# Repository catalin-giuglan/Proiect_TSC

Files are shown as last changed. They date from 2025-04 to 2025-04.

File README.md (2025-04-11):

# Proiect TSC

### Schema bloc și fișierul BOM



[Tabel BOM](https://docs.google.com/spreadsheets/d/16zDlMAK-QEJo3e8-mDt3CT91WrjNDixEgXfPSYE8hOI/edit?usp=sharing)

### Componentele au fost procurate de pe:
- [Mouser](https://eu.mouser.com/)
- [Comet](https://www.comet.srl.ro/)

### Examinare 3D a dispozitivului:
- Sketch 43 reprezintă bateria.
- Sketch 44 reprezintă ecranul.
- Pentru a vedea imagini cu dispozitivul, caută în directorul Images al acestui repository.

---

# **Descriere Proiect**  

Acest proiect constă în dezvoltarea unui ebook reader, utilizând **Autodesk Fusion** pentru modelare 3D și **librăria Desk Assistant** pentru proiectarea electronică. În cele ce urmează sunt prezentate etapele principale ale realizării proiectului, de la montarea schematicului, până la integrarea finală și generarea fișierelor necesare.

---

## **1. Instalarea librăriei Desk Assistant**  
Proiectul a început prin instalarea librăriei **Desk Assistant**, care oferă acces la componentele esențiale: rezistențe, condensatori, butoane etc. Această librărie a constituit baza pentru proiectarea și implementarea electronică.

---

## **2. Crearea schematicului**  
Am realizat schematicul în format 2D, conectând cu precizie toate componentele conform cerințelor proiectului. Procesul a inclus:  
- **Respectarea topologiilor și conexiunilor** specificate.  
- Crearea unui design clar pentru implementarea ulterioară a PCB-ului.

---

## **3. Implementarea PCB-ului**  
După finalizarea schematicului, am trecut la proiectarea plăcii PCB (layout-ul):  
- **Poziționarea componentelor** conform dimensiunilor și constrângerilor.  
- **Rutarea circuitelor** pentru conexiuni optime.  
- Validarea designului prin **fișierul DRC** (Design Rule Check), respectând toate constrângerile, cum ar fi grosimea cablurilor pentru fiabilitate.

---

## **4. Modelarea 3D**  
Am creat modelul 3D al proiectului utilizând Autodesk Fusion:  
1. Descărcarea și poziționarea **modelelor 3D** ale componentelor.  
2. Maparea acestora cu corespondențele lor din schematicul 2D.  
3. Integrarea plăcii PCB, bateriei și a display-ului în **carcasa proiectată**.

---

## **5. Generarea fișierelor auxiliare**  
Pentru livrarea proiectului, am generat:  
- **Fișierul BOM** (Bill of Materials), care include lista componentelor utilizate.  
- **Fișierul CAM**, necesar pentru fabricarea plăcii PCB.

## **6. Rezolvarea Issue-urilor semnalate**
Pentru a finaliza a doua etapa a proiectului am:
- Citit cu atentie fiecare issue
- Rezolvat problemele semnalate
- Incarcat din nou fisierele de schematic si PCB
- Incarcat imagini noi care sa demonstreze actualizarea proiectului

---

### Componente Hardware folosite:
- **ESP32-C6**: Microcontroller principal, care asigură conectivitatea și procesarea datelor.
- **E-Paper Display**: Display cu consum redus de energie, conectat prin interfața SPI.
- **Senzor de Mediu BME688**: Măsoară parametrii de mediu și trimite date prin interfața I2C.
- **Memorie NOR Flash 64MB**: Stocare extensibilă pentru fișiere de e-book.
- **Modul RTC DS3231SN**: Oferă funcționalitate de ceas în timp real.
- **Conector USB-C**: Încărcare și transfer de date.
- **Baterie Li-Po**: Alimentare principală a dispozitivului.
- **Conectori pentru SD Card**: Pentru extinderea memoriei și stocarea cărților.

---

### ESP32-C6:
- **GPIO pinii** sunt utilizați pentru conectarea senzorilor și a altor componente periferice.
- **SPI** pentru E-Paper și memorie Flash.
- **I2C** pentru senzorul de mediu.

**Interfețe principale:**
- **SPI**: Conectează ecranul E-Paper și memoria Flash.
- **I2C**: Conectează senzorul BME688 și modulul RTC.
- **UART**: Pentru comunicație serială.

**Pini Utilizați - ESP32-C6:**
- **GPIO16**: TX pentru comunicație serială.
- **GPIO17**: RX pentru comunicație serială.
- **GPIO21**: SDA pentru I2C.
- **GPIO22**: SCL pentru I2C.
- **GPIO18, GPIO19**: SCK și MISO pentru SPI.
- **GPIO5**: Chip Select pentru memorie Flash.
- **GPIO4**: Reset pentru E-Paper.

---

### Probleme și gestionarea erorilor:
- A fost necesara aprobarea a 2 erori de tip "smd-hole", deoarece o piesa era defecta.

- Pentru TP-uri nu am gasit un model 3D online, asa ca a fost nevoie sa folosesc un cilindru cu partea de sus putin rotunjita.

- Am folosit un numar de vias-uri cam mare pentru a evita erorile de overlap.

---

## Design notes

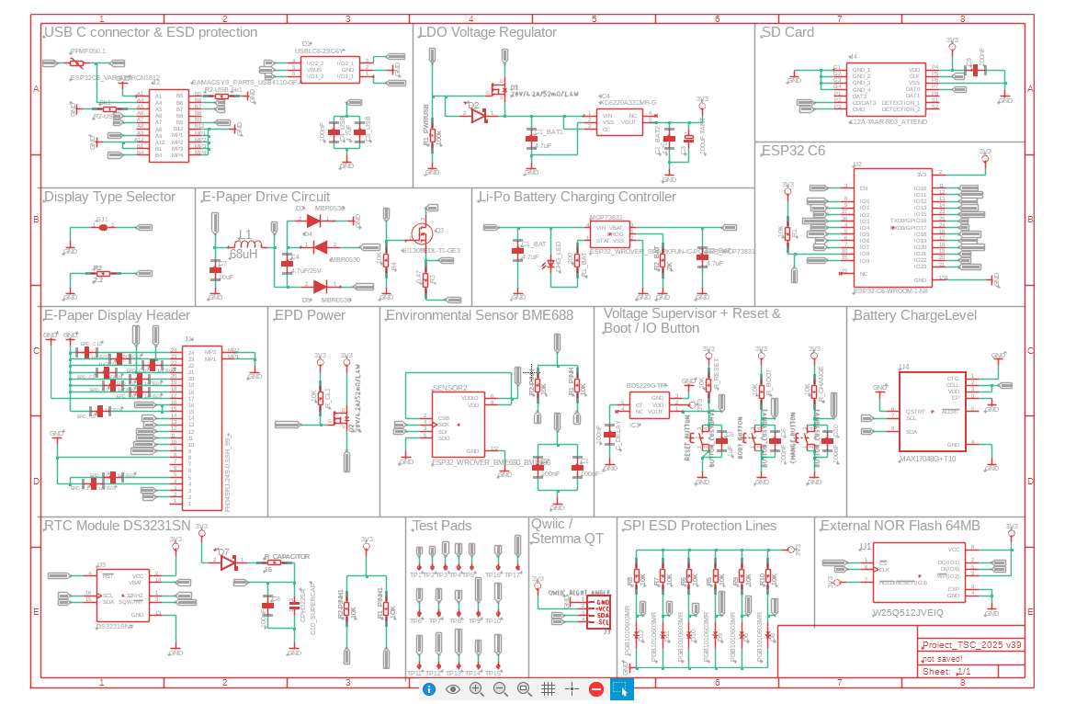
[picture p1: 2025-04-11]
Images/Schematic.png

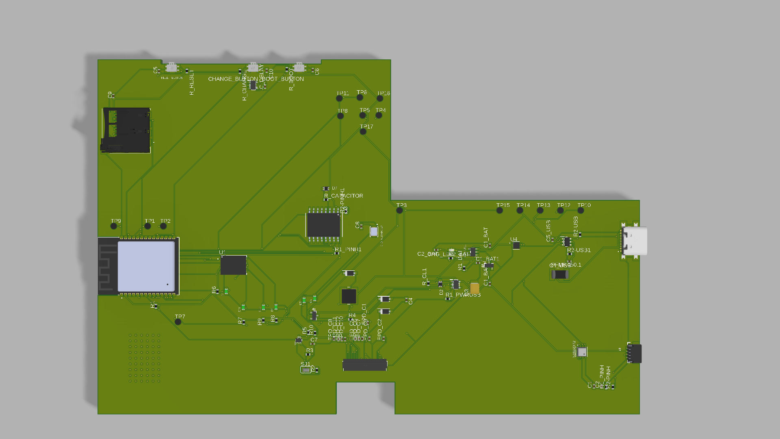
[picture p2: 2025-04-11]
Images/Proiect_TSC_2025 v38_Top.png

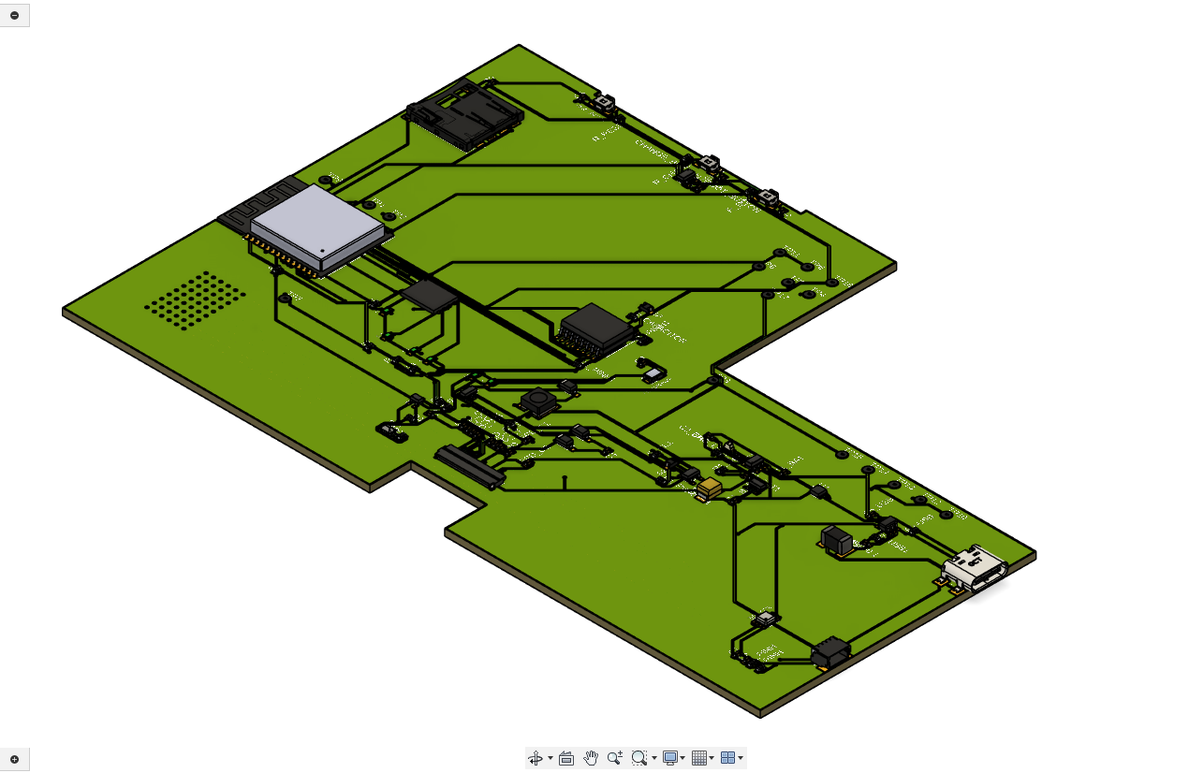
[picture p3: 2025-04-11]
Images/3D.png

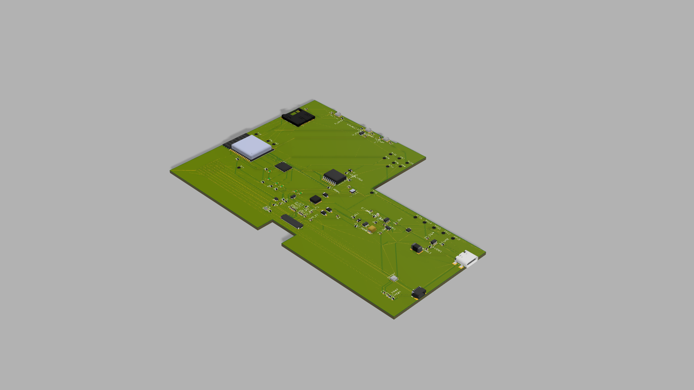
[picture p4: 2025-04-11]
Images/Proiect_TSC_2025 v38.png

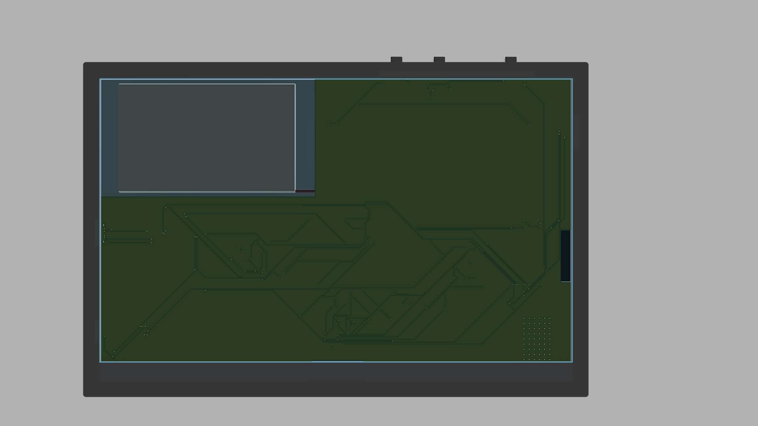
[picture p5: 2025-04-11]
Images/OpenBook Enclosure v10.png

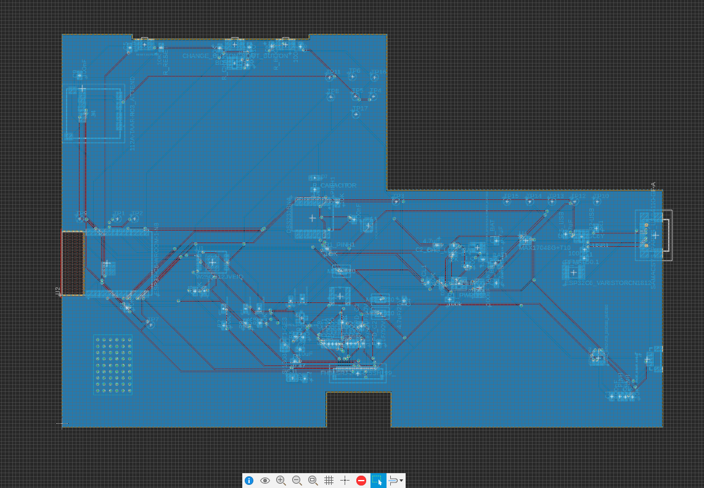
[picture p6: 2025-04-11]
Images/PCB_Bottom.png

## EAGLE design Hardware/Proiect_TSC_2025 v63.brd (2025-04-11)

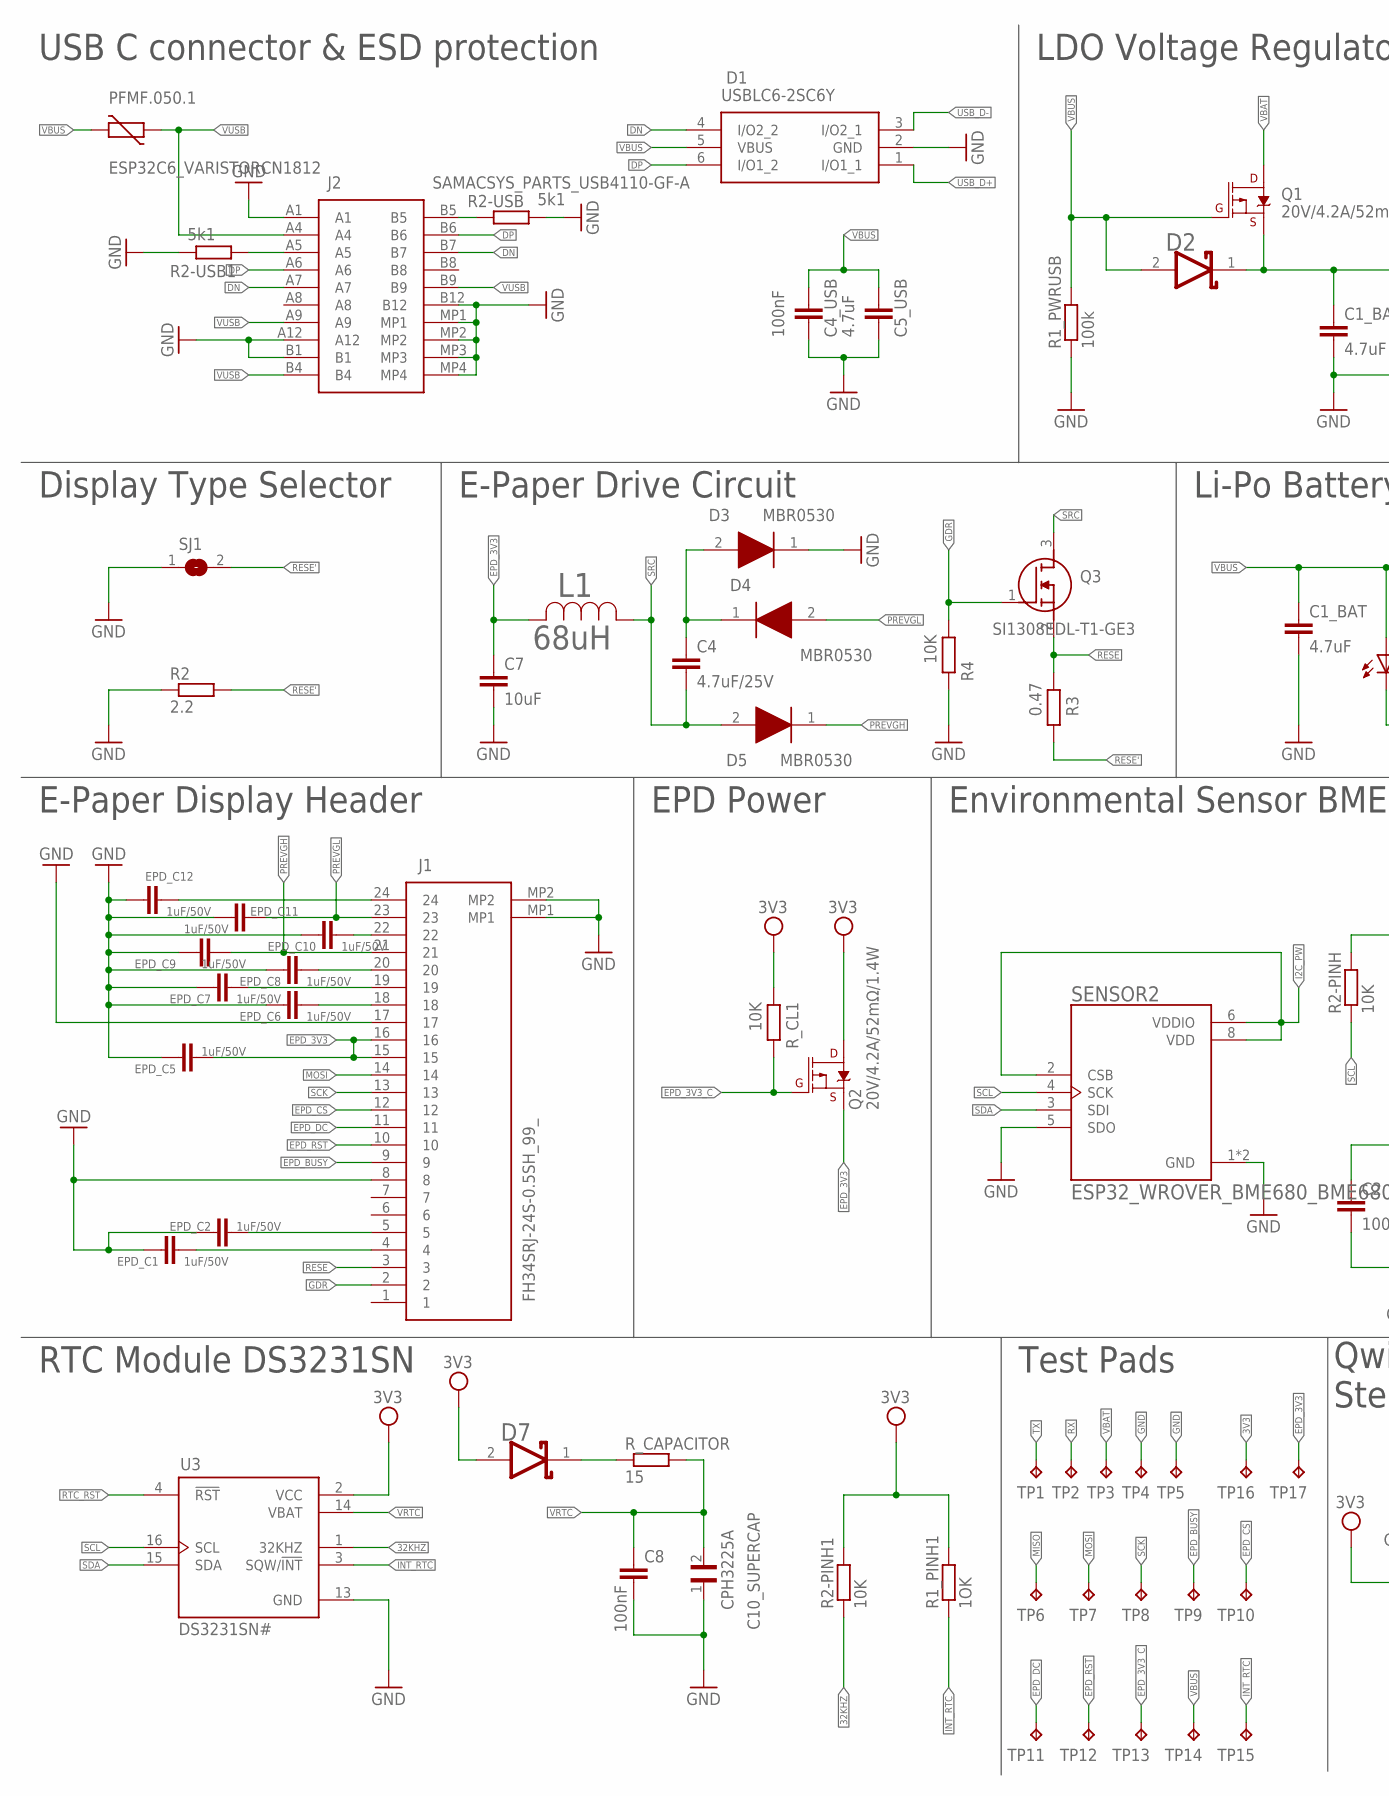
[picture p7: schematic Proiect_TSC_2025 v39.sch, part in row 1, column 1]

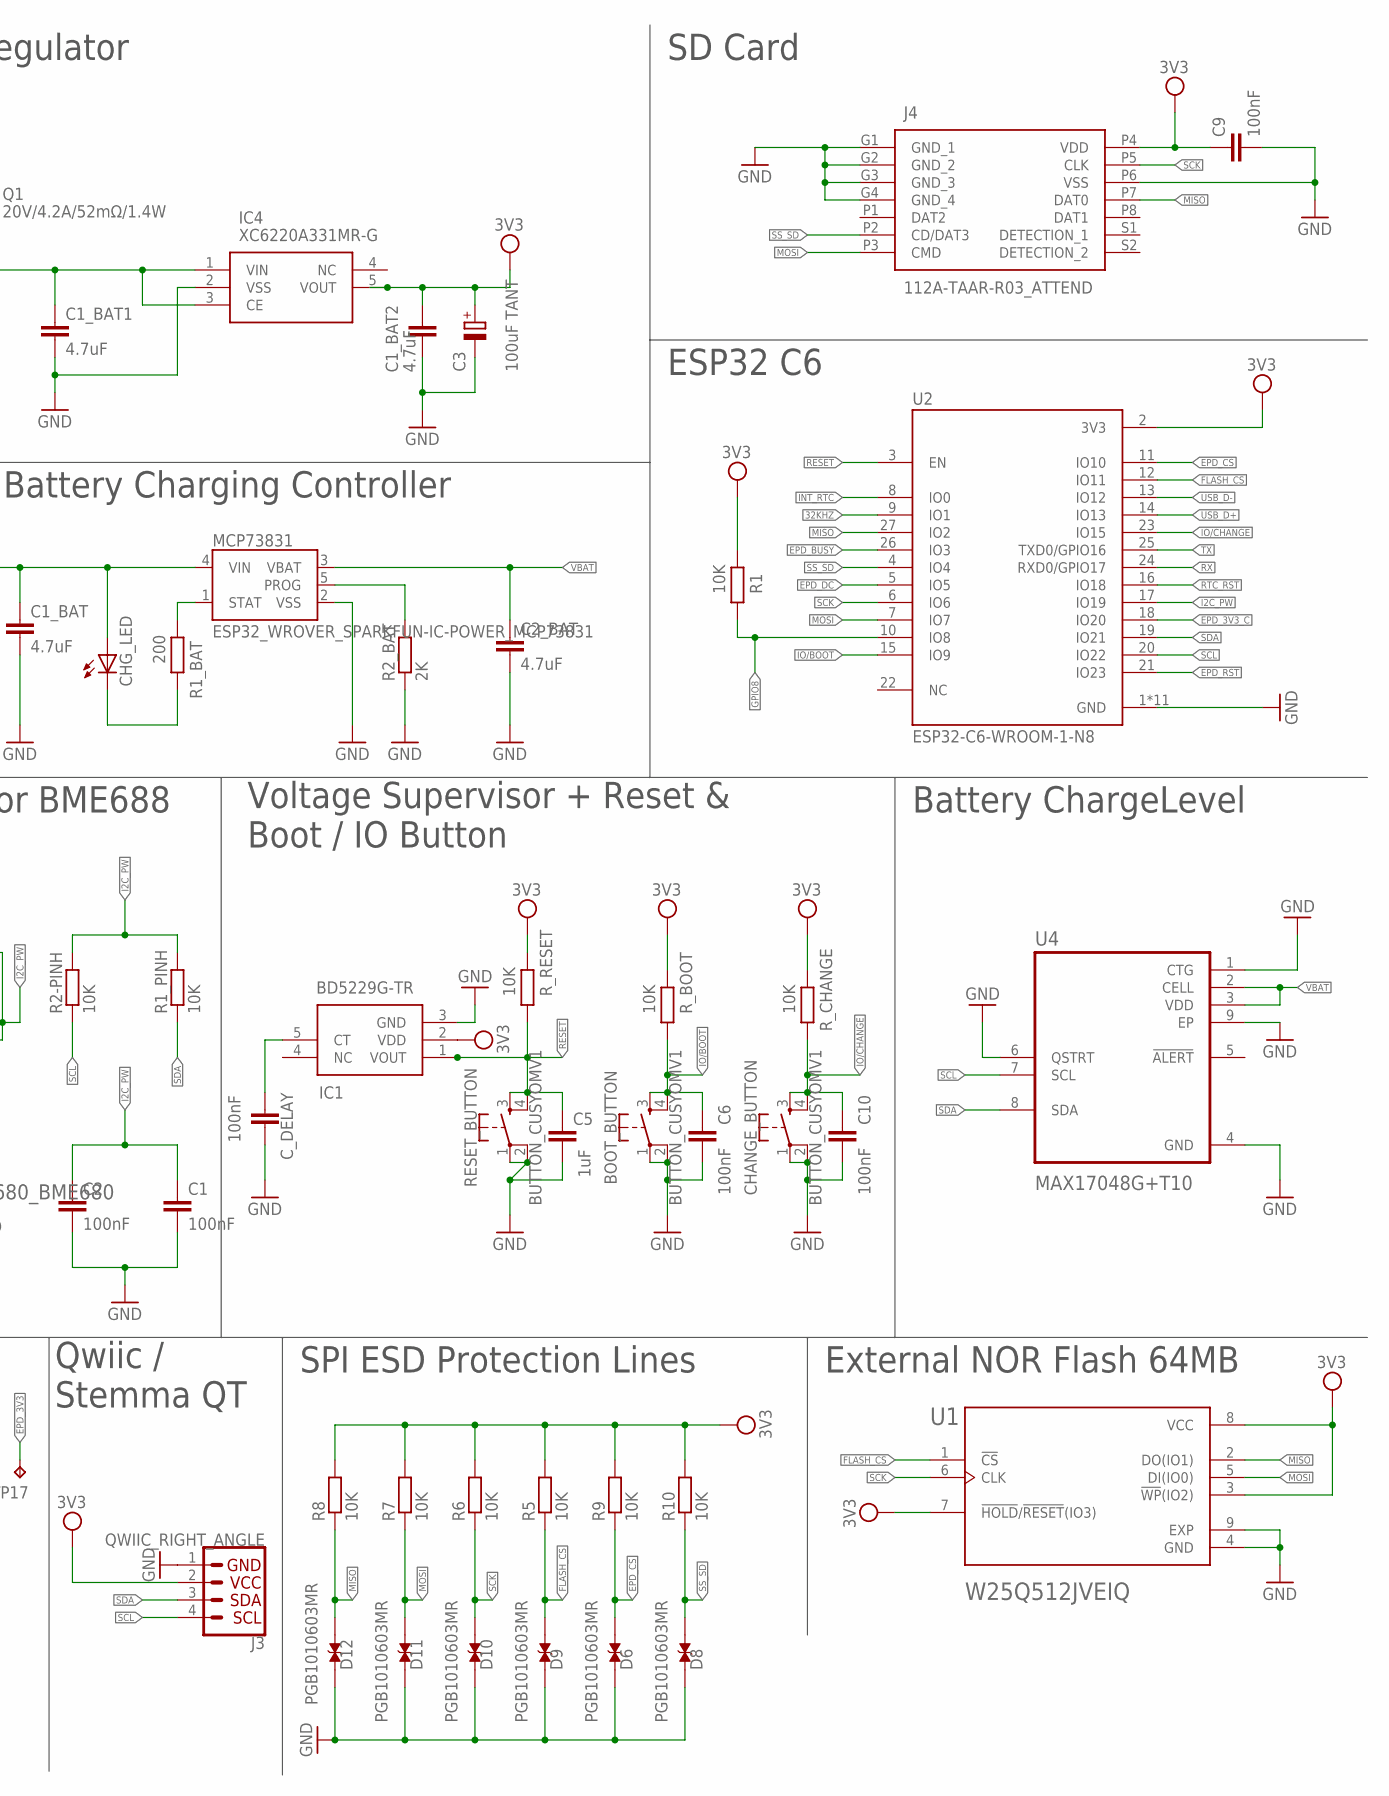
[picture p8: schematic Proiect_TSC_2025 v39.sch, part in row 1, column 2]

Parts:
BOOT_BUTTON: BUTTON_CUSYOMV1; MYBUTTON
C1, C2, C4_USB, C6, C8, C9, C10: 100nF; EAGLE-LTSPICE_C0402
C1_BAT, C1_BAT1, C1_BAT2, C2_BAT, C5_USB: 4.7uF; EAGLE-LTSPICE_C0402
C3: 100uF TANT; RCL_CT3528
C4: 4.7uF/25V; EAGLE-LTSPICE_C0402
C5: 1uF; EAGLE-LTSPICE_C0402
C7: 10uF; EAGLE-LTSPICE_C0402
C10_SUPERCAP: CPH3225A; CAPCP3225X100N
CHANGE_BUTTON: BUTTON_CUSYOMV1; MYBUTTON
CHG_LED: ADAFRUIT_LEDCHIP-LED0603; ADAFRUIT_CHIP-LED0603
C_DELAY: 100nF; EAGLE-LTSPICE_C0402
D1: USBLC6-2SC6Y; SOT95P280X145-6N
D2, D7: ESP32_WROVER_AVX---SD0805S020S1R0_AVX_SD0805S020S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; ESP32_WROVER_AVX---SD0805S020S1R0_AVX_SD0805S020S1R0_0
D3, D4, D5: MBR0530; SOD3716X135N
D6, D8, D9, D10, D11, D12: PGB1010603MR; DIOC1608X36N
EPD_C1, EPD_C2, EPD_C5, EPD_C6, EPD_C7, EPD_C8, EPD_C9, EPD_C10, EPD_C11, EPD_C12: 1uF/50V; EAGLE-LTSPICE_C0402
IC1: BD5229G-TR; SOT95P280X125-5N
IC4: XC6220A331MR-G; SOT95P280X120-5N
J1: FH34SRJ-24S-0.5SH_99_; FH34SRJ24S05SH99
J2: SAMACSYS_PARTS_USB4110-GF-A; SAMACSYS_PARTS_USB4110GFA
J3: QWIIC_RIGHT_ANGLE; JST04_1MM_VERT
J4: 112A-TAAR-R03_ATTEND; 112ATAARR03ATTEND
L1: 68uH; IND_4828-WE-TPC_WRE
MCP73831: ESP32_WROVER_SPARKFUN-IC-POWER_MCP73831; ESP32_WROVER_SPARKFUN-IC-POWER_SOT23-5
PFMF.050.1: ESP32C6_VARISTORCN1812; ESP32C6_VARISTOR_CT/CN1812
Q1, Q2: 20V/4.2A/52mΩ/1.4W; ESP32_WROVER_SPARKFUN-DISCRETESEMI_SOT23-3
Q3: SI1308EDL-T1-GE3; SOT65P210X110-3N
R1, R1_PINH, R2-PINH, R2-PINH1, R4, R5, R6, R7, R8, R9, R10: 10K; ESP32_WROVER_EAGLE-LTSPICE_R0402
R1_BAT: 200; ESP32_WROVER_EAGLE-LTSPICE_R0402
R1_PINH1: 1OK; ESP32_WROVER_EAGLE-LTSPICE_R0402
R1_PWRUSB: 100k; ESP32_WROVER_EAGLE-LTSPICE_R0402
R2: 2.2; ESP32_WROVER_EAGLE-LTSPICE_R0402
R2-USB, R2-USB1: 5k1; ESP32_WROVER_EAGLE-LTSPICE_R0402
R2_BAT: 2K; ESP32_WROVER_EAGLE-LTSPICE_R0402
R3: 0.47; ESP32_WROVER_EAGLE-LTSPICE_R0402
RESET_BUTTON: BUTTON_CUSYOMV1; MYBUTTON
R_BOOT: 10K; ESP32_WROVER_EAGLE-LTSPICE_R0402
R_CAPACITOR: 15; ESP32_WROVER_EAGLE-LTSPICE_R0402
R_CHANGE: 10K; ESP32_WROVER_EAGLE-LTSPICE_R0402
R_CL1: 10K; ESP32_WROVER_EAGLE-LTSPICE_R0402
R_RESET: 10K; ESP32_WROVER_EAGLE-LTSPICE_R0402
SENSOR2: ESP32_WROVER_BME680_BME680; ESP32_WROVER_BME680_PSON80P300X300X100-8N
SJ1: SJ
TP1, TP2, TP3, TP4, TP5, TP6, TP7, TP8, TP9, TP10, TP11, TP12, TP13, TP14, TP15, TP16, TP17: TPTP20R; TP20R
U1: W25Q512JVEIQ; SON127P600X800X80-9N
U2: ESP32-C6-WROOM-1-N8; XCVR_ESP32-C6-WROOM-1-N8
U3: DS3231SN#; SOIC127P1032X265-16N
U4: MAX17048G+T10; SON50P200X200X80-9N

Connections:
3V3: C1_BAT2.1, C3.+, C9.1, D7.2 (ANODE), IC1.2 (VDD), IC4.5 (VOUT), J3.2, J4.P4 (VDD), Q2.3 (D), R1.2, R1_PINH1.2, R2-PINH1.2, R5.2, R6.2, R7.2, R8.2, R9.2, R10.2, R_BOOT.2, R_CHANGE.2, R_CL1.2, R_RESET.2, TP16.TP, U1.3 (!WP!(IO2)), U1.7 (!HOLD!/!RESET!(IO3)), U1.8 (VCC), U2.2 (3V3), U3.2 (VCC)
32KHZ: R2-PINH1.1, U2.9 (IO1), U3.1 (32KHZ)
DN: D1.4 (I/O2_2), J2.A7, J2.B7
DP: D1.6 (I/O1_2), J2.A6, J2.B6
EPD_3V3: C7.1, EPD_C5.2, J1.15, J1.16, L1.2, Q2.2 (S), TP17.TP
EPD_3V3_C: Q2.1 (G), R_CL1.1, TP13.TP, U2.18 (IO20)
EPD_BUSY: J1.9, TP9.TP, U2.26 (IO3)
EPD_CS: D6.2, J1.12, R9.1, TP10.TP, U2.11 (IO10)
EPD_DC: J1.11, TP11.TP, U2.5 (IO5)
EPD_RST: J1.10, TP12.TP, U2.21 (IO23)
FLASH_CS: D9.2, R5.1, U1.1 (!CS), U2.12 (IO11)
GDR: J1.2, Q3.1 (G), R4.2
GND: BOOT_BUTTON.1, BOOT_BUTTON.2, C1.2, C1_BAT.2, C1_BAT1.2, C1_BAT2.2, C2.2, C2_BAT.2, C3.-, C4_USB.2, C5.2, C5_USB.2, C6.2, C7.2, C8.2, C9.2, C10.2, C10_SUPERCAP.1, CHANGE_BUTTON.1, CHANGE_BUTTON.2, C_DELAY.2, D1.2 (GND), D3.1 (K), D6.1, D8.1, D9.1, D10.1, D11.1, D12.1, EPD_C1.1, EPD_C2.1, EPD_C5.1, EPD_C6.1, EPD_C7.1, EPD_C8.1, EPD_C9.1, EPD_C10.1, EPD_C11.1, EPD_C12.1, IC1.3 (GND), IC4.2 (VSS), J1.8, J1.17, J1.MP1, J1.MP2, J2.A1, J2.A12, J2.B1, J2.B12, J2.MP1, J2.MP2, J2.MP3, J2.MP4, J3.1, J4.G1 (GND_1), J4.G2 (GND_2), J4.G3 (GND_3), J4.G4 (GND_4), J4.P6 (VSS), MCP73831.2 (VSS), R1_PWRUSB.1, R2.1, R2-USB.2, R2-USB1.1, R2_BAT.1, R4.1, RESET_BUTTON.1, RESET_BUTTON.2, SENSOR2.1 (GND), SENSOR2.5 (SDO), SENSOR2.7 (GND), SJ1.1, TP4.TP, TP5.TP, U1.4 (GND), U1.9 (EXP), U2.1 (GND), U2.28 (GND), U2.29_1 (GND), U2.29_2 (GND), U2.29_3 (GND), U2.29_4 (GND), U2.29_5 (GND), U2.29_6 (GND), U2.29_7 (GND), U2.29_8 (GND), U2.29_9 (GND), U3.13 (GND), U4.1 (CTG), U4.4 (GND), U4.6 (QSTRT), U4.9 (EP)
GPIO8: R1.1, U2.10 (IO8)
I2C_PW: C1.1, C2.1, R1_PINH.2, R2-PINH.2, SENSOR2.2 (CSB), SENSOR2.6 (VDDIO), SENSOR2.8 (VDD), U2.17 (IO19)
INT_RTC: R1_PINH1.1, TP15.TP, U2.8 (IO0), U3.3 (SQW/!INT)
IO/BOOT: BOOT_BUTTON.3, BOOT_BUTTON.4, C6.1, R_BOOT.1, U2.15 (IO9)
IO/CHANGE: C10.1, CHANGE_BUTTON.3, CHANGE_BUTTON.4, R_CHANGE.1, U2.23 (IO15)
MISO: D12.2, J4.P7 (DAT0), R8.1, TP6.TP, U1.2 (DO(IO1)), U2.27 (IO2)
MOSI: D11.2, J1.14, J4.P3 (CMD), R7.1, TP7.TP, U1.5 (DI(IO0)), U2.7 (IO7)
unnamed: J2.A5, R2-USB1.2
unnamed: C1_BAT1.1, D2.1 (CATHODE), IC4.1 (VIN), IC4.3 (CE), Q1.2 (S)
unnamed: J2.B5, R2-USB.1
unnamed: CHG_LED.C, R1_BAT.1
unnamed: MCP73831.1 (STAT), R1_BAT.2
unnamed: C4.1, D3.2 (A), D4.1 (K)
unnamed: MCP73831.5 (PROG), R2_BAT.2
unnamed: EPD_C1.2, J1.4
unnamed: EPD_C2.2, J1.5
unnamed: D7.1 (CATHODE), R_CAPACITOR.1
unnamed: C_DELAY.1, IC1.5 (CT)
unnamed: EPD_C6.2, J1.18
unnamed: EPD_C7.2, J1.19
unnamed: EPD_C8.2, J1.20
unnamed: EPD_C10.2, J1.22
unnamed: EPD_C12.2, J1.24
PREVGL: D4.2 (A), EPD_C11.2, J1.23
RESE: J1.3, Q3.2 (S), R3.2
RESE': R2.2, R3.1, SJ1.2
RESET: C5.1, IC1.1 (VOUT), RESET_BUTTON.3, RESET_BUTTON.4, R_RESET.1, U2.3 (EN)
RTC_RST: U2.16 (IO18), U3.4 (!RST)
RX: TP2.TP, U2.24 (RXD0/GPIO17)
SCK: D10.2, J1.13, J4.P5 (CLK), R6.1, TP8.TP, U1.6 (CLK), U2.6 (IO6)
SCL: J3.4, R2-PINH.1, SENSOR2.4 (SCK), U2.20 (IO22), U3.16 (SCL), U4.7 (SCL)
SDA: J3.3, R1_PINH.1, SENSOR2.3 (SDI), U2.19 (IO21), U3.15 (SDA), U4.8 (SDA)
SRC: C4.2, D5.2 (A), L1.1, Q3.3 (D)
SS_SD: D8.2, J4.P2 (CD/DAT3), R10.1, U2.4 (IO4)
TX: TP1.TP, U2.25 (TXD0/GPIO16)
USB_D+: D1.1 (I/O1_1), U2.14 (IO13)
USB_D-: D1.3 (I/O2_1), U2.13 (IO12)
VBAT: C2_BAT.1, MCP73831.3 (VBAT), Q1.3 (D), TP3.TP, U4.2 (CELL), U4.3 (VDD)
VBUS: C1_BAT.1, C4_USB.1, C5_USB.1, CHG_LED.A, D1.5 (VBUS), D2.2 (ANODE), MCP73831.4 (VIN), PFMF.050.1.2, Q1.1 (G), R1_PWRUSB.2, TP14.TP
VRTC: C8.1, C10_SUPERCAP.2, R_CAPACITOR.2, U3.14 (VBAT)
VUSB: J2.A4, J2.A9, J2.B4, J2.B9, PFMF.050.1.1

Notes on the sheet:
USB C connector & ESD protection
LDO Voltage Regulator
SD Card
ESP32 C6
Display Type Selector
E-Paper Drive Circuit
Li-Po Battery Charging Controller
E-Paper Display Header
EPD Power
RTC Module DS3231SN
Environmental Sensor BME688
Voltage Supervisor + Reset & Boot / IO Button
Battery ChargeLevel
Test Pads
Qwiic / Stemma QT
External NOR Flash 64MB
SPI ESD Protection Lines

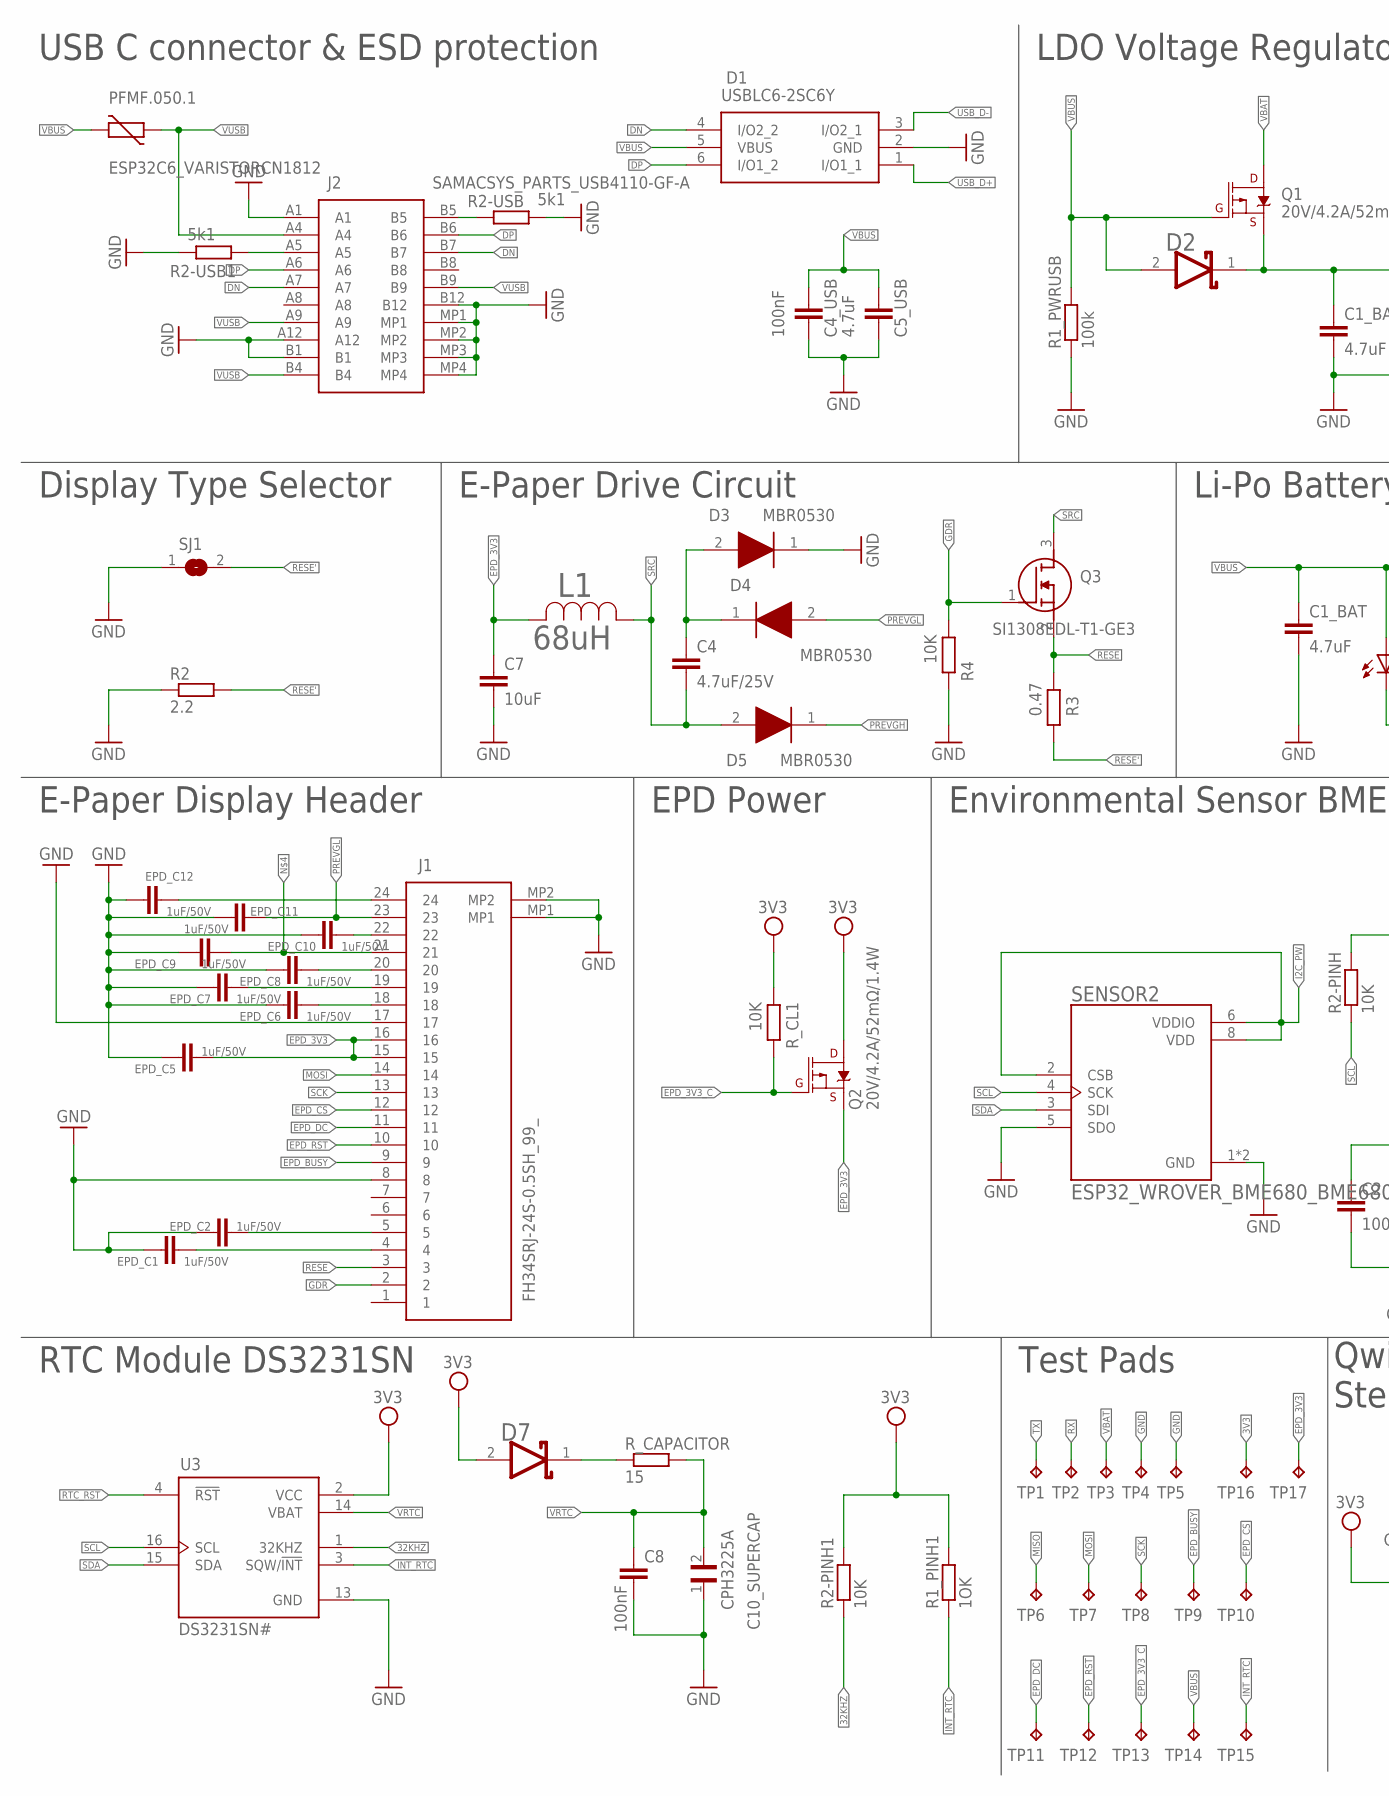
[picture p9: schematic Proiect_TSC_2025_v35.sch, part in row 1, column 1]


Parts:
BOOT_BUTTON: BUTTON_CUSYOMV1; MYBUTTON
C1, C2, C4_USB, C6, C8, C9, C10: 100nF; EAGLE-LTSPICE_C0402
C1_BAT, C1_BAT1, C1_BAT2, C2_BAT, C5_USB: 4.7uF; EAGLE-LTSPICE_C0402
C3: 100uF TANT; RCL_CT3528
C4: 4.7uF/25V; EAGLE-LTSPICE_C0402
C5: 1uF; EAGLE-LTSPICE_C0402
C7: 10uF; EAGLE-LTSPICE_C0402
C10_SUPERCAP: CPH3225A; CAPCP3225X100N
CHANGE_BUTTON: BUTTON_CUSYOMV1; MYBUTTON
CHG_LED: ADAFRUIT_LEDCHIP-LED0603; ADAFRUIT_CHIP-LED0603
C_DELAY: 100nF; EAGLE-LTSPICE_C0402
D1: USBLC6-2SC6Y; SOT95P280X145-6N
D2, D7: ESP32_WROVER_AVX---SD0805S020S1R0_AVX_SD0805S020S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; ESP32_WROVER_AVX---SD0805S020S1R0_AVX_SD0805S020S1R0_0
D3, D4, D5: MBR0530; SOD3716X135N
D6, D8, D9, D10, D11, D12: PGB1010603MR; DIOC1608X36N
EPD_C1, EPD_C2, EPD_C5, EPD_C6, EPD_C7, EPD_C8, EPD_C9, EPD_C10, EPD_C11, EPD_C12: 1uF/50V; EAGLE-LTSPICE_C0402
IC1: BD5229G-TR; SOT95P280X125-5N
IC4: XC6220A331MR-G; SOT95P280X120-5N
J1: FH34SRJ-24S-0.5SH_99_; FH34SRJ24S05SH99
J2: SAMACSYS_PARTS_USB4110-GF-A; SAMACSYS_PARTS_USB4110GFA
J3: QWIIC_RIGHT_ANGLE; JST04_1MM_VERT
J4: 112A-TAAR-R03_ATTEND; 112ATAARR03ATTEND
L1: 68uH; IND_4828-WE-TPC_WRE
MCP73831: ESP32_WROVER_SPARKFUN-IC-POWER_MCP73831; ESP32_WROVER_SPARKFUN-IC-POWER_SOT23-5
PFMF.050.1: ESP32C6_VARISTORCN1812; ESP32C6_VARISTOR_CT/CN1812
Q1, Q2: 20V/4.2A/52mΩ/1.4W; ESP32_WROVER_SPARKFUN-DISCRETESEMI_SOT23-3
Q3: SI1308EDL-T1-GE3; SOT65P210X110-3N
R1, R1_PINH, R2-PINH, R2-PINH1, R4, R5, R6, R7, R8, R9, R10: 10K; ESP32_WROVER_EAGLE-LTSPICE_R0402
R1_BAT: 200; ESP32_WROVER_EAGLE-LTSPICE_R0402
R1_PINH1: 1OK; ESP32_WROVER_EAGLE-LTSPICE_R0402
R1_PWRUSB: 100k; ESP32_WROVER_EAGLE-LTSPICE_R0402
R2: 2.2; ESP32_WROVER_EAGLE-LTSPICE_R0402
R2-USB, R2-USB1: 5k1; ESP32_WROVER_EAGLE-LTSPICE_R0402
R2_BAT: 2K; ESP32_WROVER_EAGLE-LTSPICE_R0402
R3: 0.47; ESP32_WROVER_EAGLE-LTSPICE_R0402
RESET_BUTTON: BUTTON_CUSYOMV1; MYBUTTON
R_BOOT: 10K; ESP32_WROVER_EAGLE-LTSPICE_R0402
R_CAPACITOR: 15; ESP32_WROVER_EAGLE-LTSPICE_R0402
R_CHANGE: 10K; ESP32_WROVER_EAGLE-LTSPICE_R0402
R_CL1: 10K; ESP32_WROVER_EAGLE-LTSPICE_R0402
R_RESET: 10K; ESP32_WROVER_EAGLE-LTSPICE_R0402
SENSOR2: ESP32_WROVER_BME680_BME680; ESP32_WROVER_BME680_PSON80P300X300X100-8N
SJ1: SJ
TP1, TP2, TP3, TP4, TP5, TP6, TP7, TP8, TP9, TP10, TP11, TP12, TP13, TP14, TP15, TP16, TP17: TPTP20R; TP20R
U1: W25Q512JVEIQ; SON127P600X800X80-9N
U2: ESP32-C6-WROOM-1-N8; XCVR_ESP32-C6-WROOM-1-N8
U3: DS3231SN#; SOIC127P1032X265-16N
U4: MAX17048G+T10; SON50P200X200X80-9N

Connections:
3V3: C1_BAT2.1, C3.+, C9.1, D7.2 (ANODE), IC1.2 (VDD), IC4.5 (VOUT), J3.2, J4.P4 (VDD), Q2.3 (D), R1.2, R1_PINH1.2, R2-PINH1.2, R5.2, R6.2, R7.2, R8.2, R9.2, R10.2, R_BOOT.2, R_CHANGE.2, R_CL1.2, R_RESET.2, TP16.TP, U1.3 (!WP!(IO2)), U1.7 (!HOLD!/!RESET!(IO3)), U1.8 (VCC), U2.2 (3V3), U3.2 (VCC)
32KHZ: R2-PINH1.1, U2.9 (IO1), U3.1 (32KHZ)
DN: D1.4 (I/O2_2), J2.A7, J2.B7
DP: D1.6 (I/O1_2), J2.A6, J2.B6
EPD_3V3: C7.1, EPD_C5.2, J1.15, J1.16, L1.2, Q2.2 (S), TP17.TP
EPD_3V3_C: Q2.1 (G), R_CL1.1, TP13.TP, U2.18 (IO20)
EPD_BUSY: J1.9, TP9.TP, U2.26 (IO3)
EPD_CS: D6.2, J1.12, R9.1, TP10.TP, U2.11 (IO10)
EPD_DC: J1.11, TP11.TP, U2.5 (IO5)
EPD_RST: J1.10, TP12.TP, U2.21 (IO23)
FLASH_CS: D9.2, R5.1, U1.1 (!CS), U2.12 (IO11)
GDR: J1.2, Q3.1 (G), R4.2
GND: BOOT_BUTTON.1, BOOT_BUTTON.2, C1.2, C1_BAT.2, C1_BAT1.2, C1_BAT2.2, C2.2, C2_BAT.2, C3.-, C4_USB.2, C5.2, C5_USB.2, C6.2, C7.2, C8.2, C9.2, C10.2, C10_SUPERCAP.1, CHANGE_BUTTON.1, CHANGE_BUTTON.2, C_DELAY.2, D1.2 (GND), D3.1 (K), D6.1, D8.1, D9.1, D10.1, D11.1, D12.1, EPD_C1.1, EPD_C2.1, EPD_C5.1, EPD_C6.1, EPD_C7.1, EPD_C8.1, EPD_C9.1, EPD_C10.1, EPD_C11.1, EPD_C12.1, IC1.3 (GND), IC4.2 (VSS), J1.8, J1.17, J1.MP1, J1.MP2, J2.A1, J2.A12, J2.B1, J2.B12, J2.MP1, J2.MP2, J2.MP3, J2.MP4, J3.1, J4.G1 (GND_1), J4.G2 (GND_2), J4.G3 (GND_3), J4.G4 (GND_4), J4.P6 (VSS), MCP73831.2 (VSS), R1_PWRUSB.1, R2.1, R2-USB.2, R2-USB1.1, R2_BAT.1, R4.1, RESET_BUTTON.1, RESET_BUTTON.2, SENSOR2.1 (GND), SENSOR2.5 (SDO), SENSOR2.7 (GND), SJ1.1, TP4.TP, TP5.TP, U1.4 (GND), U1.9 (EXP), U2.1 (GND), U2.28 (GND), U2.29_1 (GND), U2.29_2 (GND), U2.29_3 (GND), U2.29_4 (GND), U2.29_5 (GND), U2.29_6 (GND), U2.29_7 (GND), U2.29_8 (GND), U2.29_9 (GND), U3.13 (GND), U4.1 (CTG), U4.4 (GND), U4.6 (QSTRT), U4.9 (EP)
GPIO8: R1.1, U2.10 (IO8)
I2C_PW: C1.1, C2.1, R1_PINH.2, R2-PINH.2, SENSOR2.2 (CSB), SENSOR2.6 (VDDIO), SENSOR2.8 (VDD), U2.17 (IO19)
INT_RTC: R1_PINH1.1, TP15.TP, U2.8 (IO0), U3.3 (SQW/!INT)
IO/BOOT: BOOT_BUTTON.3, BOOT_BUTTON.4, C6.1, R_BOOT.1, U2.15 (IO9)
IO/CHANGE: C10.1, CHANGE_BUTTON.3, CHANGE_BUTTON.4, R_CHANGE.1, U2.23 (IO15)
MISO: D12.2, J4.P7 (DAT0), R8.1, TP6.TP, U1.2 (DO(IO1)), U2.27 (IO2)
MOSI: D11.2, J1.14, J4.P3 (CMD), R7.1, TP7.TP, U1.5 (DI(IO0)), U2.7 (IO7)
unnamed: J2.A5, R2-USB1.2
unnamed: C1_BAT1.1, D2.1 (CATHODE), IC4.1 (VIN), IC4.3 (CE), Q1.2 (S)
unnamed: J2.B5, R2-USB.1
unnamed: CHG_LED.C, R1_BAT.1
unnamed: MCP73831.1 (STAT), R1_BAT.2
unnamed: C4.1, D3.2 (A), D4.1 (K)
unnamed: MCP73831.5 (PROG), R2_BAT.2
unnamed: EPD_C1.2, J1.4
unnamed: EPD_C2.2, J1.5
unnamed: D7.1 (CATHODE), R_CAPACITOR.1
unnamed: C_DELAY.1, IC1.5 (CT)
unnamed: EPD_C6.2, J1.18
unnamed: EPD_C7.2, J1.19
unnamed: EPD_C8.2, J1.20
unnamed: EPD_C10.2, J1.22
unnamed: EPD_C12.2, J1.24
PREVGL: D4.2 (A), EPD_C11.2, J1.23
RESE: J1.3, Q3.2 (S), R3.2
RESE': R2.2, R3.1, SJ1.2
RESET: C5.1, IC1.1 (VOUT), RESET_BUTTON.3, RESET_BUTTON.4, R_RESET.1, U2.3 (EN)
RTC_RST: U2.16 (IO18), U3.4 (!RST)
RX: TP2.TP, U2.24 (RXD0/GPIO17)
SCK: D10.2, J1.13, J4.P5 (CLK), R6.1, TP8.TP, U1.6 (CLK), U2.6 (IO6)
SCL: J3.4, R2-PINH.1, SENSOR2.4 (SCK), U2.20 (IO22), U3.16 (SCL), U4.7 (SCL)
SDA: J3.3, R1_PINH.1, SENSOR2.3 (SDI), U2.19 (IO21), U3.15 (SDA), U4.8 (SDA)
SRC: C4.2, D5.2 (A), L1.1, Q3.3 (D)
SS_SD: D8.2, J4.P2 (CD/DAT3), R10.1, U2.4 (IO4)
TX: TP1.TP, U2.25 (TXD0/GPIO16)
USB_D+: D1.1 (I/O1_1), U2.14 (IO13)
USB_D-: D1.3 (I/O2_1), U2.13 (IO12)
VBAT: C2_BAT.1, MCP73831.3 (VBAT), Q1.3 (D), TP3.TP, U4.2 (CELL), U4.3 (VDD)
VBUS: C1_BAT.1, C4_USB.1, C5_USB.1, CHG_LED.A, D1.5 (VBUS), D2.2 (ANODE), MCP73831.4 (VIN), PFMF.050.1.2, Q1.1 (G), R1_PWRUSB.2, TP14.TP
VRTC: C8.1, C10_SUPERCAP.2, R_CAPACITOR.2, U3.14 (VBAT)
VUSB: J2.A4, J2.A9, J2.B4, J2.B9, PFMF.050.1.1

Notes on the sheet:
USB C connector & ESD protection
LDO Voltage Regulator
SD Card
ESP32 C6
Display Type Selector
E-Paper Drive Circuit
Li-Po Battery Charging Controller
E-Paper Display Header
EPD Power
RTC Module DS3231SN
Environmental Sensor BME688
Voltage Supervisor + Reset & Boot / IO Button
Battery ChargeLevel
Test Pads
Qwiic / Stemma QT
External NOR Flash 64MB
SPI ESD Protection Lines

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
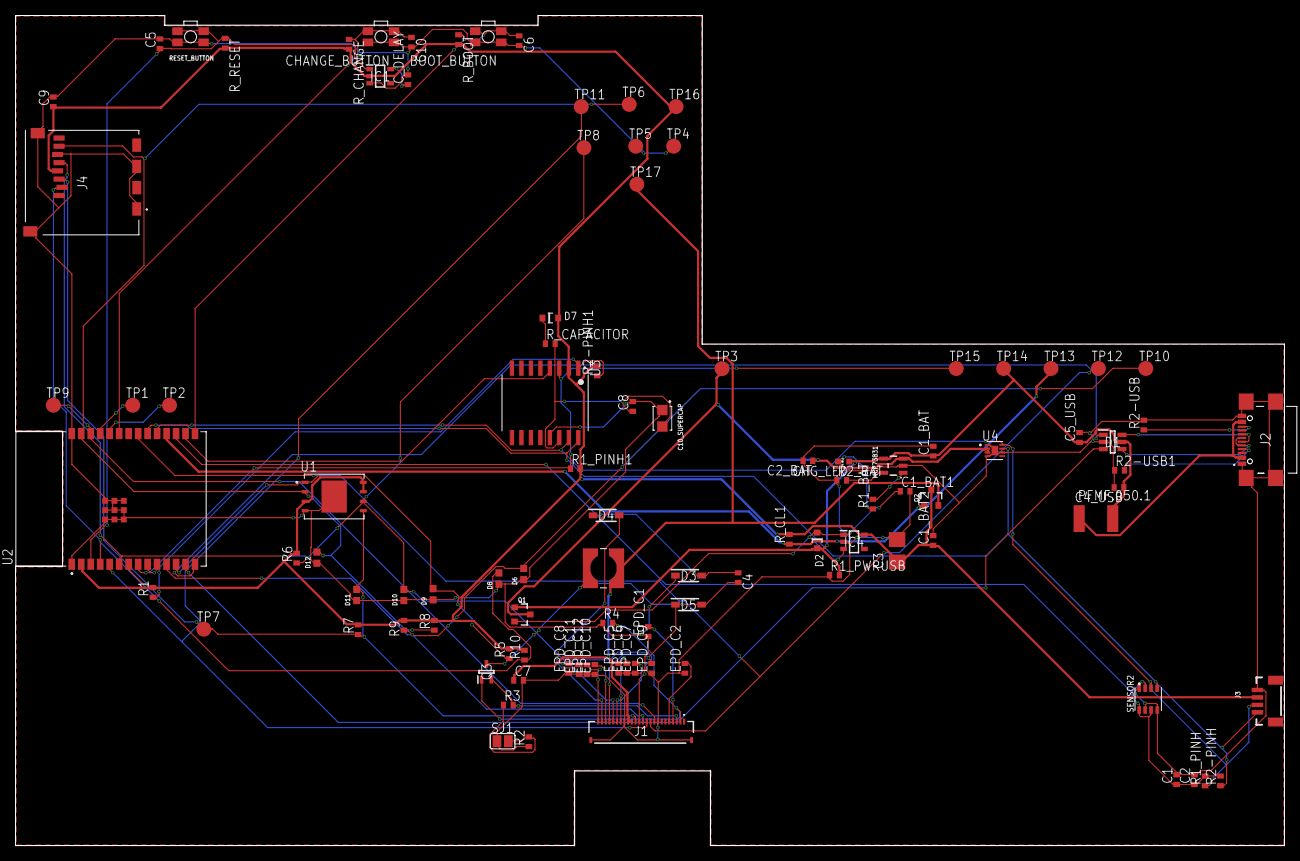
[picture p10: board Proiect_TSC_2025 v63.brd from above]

Board: 2 copper layers, 170.0 x 111.2 mm, 103 parts (0 on the bottom side), 55 nets.

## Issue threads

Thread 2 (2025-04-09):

PCB - Probleme ESP32

Ato2207, 2025-04-09:
1. Modulul ESP32 ar trebui sa fie aliniat cu marginea PCB-ului.
2. Board-ul ar trebui decupat sub antena ESP32-ului(dreptunghiul incercuit), astfel incat semnalele sa nu fie rutate sub aceasta si sa nu fie inclusa in planul de masa.

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

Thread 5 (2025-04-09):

PCB - Probleme silkscreen

Ato2207, 2025-04-09:
1. Silkscreen-ul nu ar trebui sa contina si valorile componentelor(spre exemplu la rezistente, condensatoarea, etc.).De asemenea, numele ar trebui asezate si redimensionate corespunzator astfel incat sa poata fi citite usor de pe placa.
2. Testpad-urile ar trebui sa fie marcate clar pe PCB cu denumirile semnalelor pe care le poarta.Uite un exemplu aici:

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

Closed 2025-04-14.

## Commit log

2025-04-06 Upload Proiect
    [PnP_Proiect_TSC_2025 v55_front.csv, Proiect_TSC_2025 v55.brd, Proiect_TSC_2025_v35.sch]
2025-04-06 Added Components Links
    [PnP_Proiect_TSC_2025 v55_front.csv]
2025-04-11 Fixed issues
    [Proiect_TSC_2025 v39.sch, Proiect_TSC_2025 v63.brd]

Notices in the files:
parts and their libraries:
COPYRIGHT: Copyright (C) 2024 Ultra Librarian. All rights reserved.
